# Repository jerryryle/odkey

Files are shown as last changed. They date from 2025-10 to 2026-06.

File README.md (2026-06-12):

# ODKey - A USB HID macro key, with a fun WiFi backdoor

You can find an explanation for this device's existence in [the docs](https://jerryryle.github.io/odkey/).

The ODKey is a hardware device featuring a single button (a [NovelKeys Big Switch](https://novelkeys.com/collections/switches/products/the-big-switch-series)), a USB interface, and a WiFi interface.

When plugged into a computer, the ODKey enumerates as a USB HID keyboard. You can press the ODKey's button to run a configurable script that sends keyboard events to the connected computer. See [ODKeyScript.md](ODKeyScript.md) for documentation on the scripting language used to send keyboard events.

The ODKey incorporates an [Adafruit Feather ESP32-S2](https://www.adafruit.com/product/5000) board. Those familiar with this product will note that, besides the USB interface, the ESP32-S2 sports a WiFi interface. And, of course, the ODKey offers WiFi functionality.

You can use both USB and WiFi to configure the ODKey and run programs.

## Overview of functionality

* The Button
    * A push/release of the ODKey button runs the current flash program (more on this below)
    * If the ODKey is held, it will repeatedly run the flash program as long as it remains held. While held, the ODKey will run the program completion, wait a configurable amount of time (as determined by the `button_repeat` setting), and then run the program again, etc. Once the button is released, any currently-running program will finish and then program execution will stop.
    * Pressing the ODKey button will not interrupt a running program. If you have uploaded a very long program and executed it by pressing the button, the only way to halt it is to physically unplug the ODKey.
    * The ODKey will not enqueue presses. When you press/release the button, two things can happen:
        * The ODKey is idle and begins executing the flash program
        * The ODKey is already executing a program and ignores the new button press.
* ODKeyScript Programs
    * ODKeyScript Programs are compiled locally using the ODKey Tools. Compiled bytecode is uploaded to the device via USB or WiFi.
    * An ODKeyScript Program can be uploaded to flash via USB or WiFi. When the button is pressed, it runs the program currently stored in flash. Flash is non-volatile storage and persists when the device is unplugged/re-plugged or otherwise rebooted.
    * An ODKeyScript Program can be uploaded to RAM and executed immediately. This is an ephemeral program meant for testing and/or remote control of a computer.
    * See [ODKeyScript.md](ODKeyScript.md) for documentation of the ODKeyScript language used to write programs.
* Configuration
    * The ODKey can be configured via USB and/or WiFi.

## Setting up the ODKey Tools on macOS

### Prerequisites

1. **Install Homebrew** (if not already installed):
   See the [Homebrew installation guide](https://brew.sh/#install).

2. **Install Python 3.12+**:
   ```bash
   # Install Python 3.12+ via Homebrew
   brew install python@3.12
   ```

3. **Install uv**:
   ```bash
   # Install uv (Python package manager) via Homebrew
   brew install uv
   ```

4. **Verify installations**:
   ```bash
   python3 --version  # Should show Python 3.12.x or higher
   uv --version       # Should show uv version
   ```

### Clone and Setup the Repository

1. **Clone the ODKey repository**:
   ```bash
   git clone git@github.com:jerryryle/odkey.git
   ```

2. **Navigate to the tools directory**:
   ```bash
   cd odkey/odkey_tools
   ```

3. **Install dependencies and setup the project**:
   ```bash
   # Install project dependencies
   uv sync
   
   # Verify the CLI is working
   uv run odkey --help
   ```

## Using the ODKey Tools
### Device Interfaces
#### USB
The USB interface provides direct communication with the ODKey device using a custom HID protocol. Use this to perform initial configuration before WiFi is set up.

#### WiFi
The WiFi interface provides access to the ODKey device via an HTTP API. This allows you to control and configure the device without a physical USB connection. By default, the ODKey device appears on the network as `odkey.local` via mDNS.

The WiFi credentials, hostname, http port, and API key are all configurable. Use the USB interface for initial setup or if you don't otherwise have WiFi connectivity.

### Device Configuration

The ODKey device stores configuration values in NVS (Non-Volatile Storage) flash memory. You can read, write, and delete these configuration keys using the CLI tools.

#### Supported Configuration Keys

| Key | Type | Description | Default |
|-----|---|---|---|
| `wifi_ssid` | string | WiFi network name (SSID) to connect to | Empty (WiFi not enabled) |
| `wifi_pw` | string | WiFi network password | Empty (WiFi not enabled) |
| `mdns_hostname` | string | mDNS hostname for network discovery | "odkey" |
| `mdns_instance` | string | mDNS instance name for device identification | "ODKey Device" |
| `http_port` | u16 | HTTP server port for WiFi API access | 80 |
| `http_api_key` | string | API key for HTTP authentication | Empty (API disabled) |
| `button_debounce` | u32 | Button debounce time in milliseconds | 50ms |
| `button_repeat` | u32 | Button repeat delay in milliseconds | 225ms |

- **WiFi Configuration**: `wifi_ssid` and `wifi_pw` control which WiFi network the device connects to. If not set, the device operates in USB-only mode.
- **mDNS Discovery**: `mdns_hostname` sets the device's network hostname (e.g., "odkey.local"). `mdns_instance` sets the friendly name shown in network discovery tools.
- **HTTP Server**: `http_port` sets the port for the WiFi API server. `http_api_key` enables authentication for all HTTP operations.
- **Button Behavior**: `button_debounce` prevents false triggers from electrical noise when the button is pressed. `button_repeat` controls how long to wait before re-running the program while the button is held.

#### Configuration Commands

```bash
# Set/get WiFi credentials
## USB
uv run odkey nvs-set wifi_ssid "MyWiFiNetwork"
uv run odkey nvs-set wifi_pw "MyWiFiPassword"

uv run odkey nvs-get wifi_ssid
uv run odkey nvs-get wifi_pw

## HTTP
uv run odkey nvs-set wifi_ssid "MyWiFiNetwork" --interface http --host odkey.local --api-key your-api-key
uv run odkey nvs-set wifi_pw "MyWiFiPassword" --interface http --host odkey.local --api-key your-api-key

uv run odkey nvs-get wifi_ssid --interface http --host odkey.local --api-key your-api-key
uv run odkey nvs-get wifi_pw --interface http --host odkey.local --api-key your-api-key

# Set/get mDNS configuration
## USB
uv run odkey nvs-set mdns_hostname "my-odkey"
uv run odkey nvs-set mdns_instance "My ODKey Device"

uv run odkey nvs-get mdns_hostname
uv run odkey nvs-get mdns_instance

## HTTP
uv run odkey nvs-set mdns_hostname "my-odkey" --interface http --host odkey.local --api-key your-api-key
uv run odkey nvs-set mdns_instance "My ODKey Device" --interface http --host odkey.local --api-key your-api-key

uv run odkey nvs-get mdns_hostname --interface http --host odkey.local --api-key your-api-key
uv run odkey nvs-get mdns_instance --interface http --host odkey.local --api-key your-api-key

# Set/get HTTP server configuration
## USB
uv run odkey nvs-set http_port 8080 --type u16
uv run odkey nvs-set http_api_key "my-secret-api-key"

uv run odkey nvs-get http_port
uv run odkey nvs-get http_api_key

## HTTP
uv run odkey nvs-set http_port 8080 --type u16 --interface http --host odkey.local --api-key your-api-key
uv run odkey nvs-set http_api_key "my-secret-api-key" --interface http --host odkey.local --api-key your-api-key

uv run odkey nvs-get http_port --interface http --host odkey.local --api-key your-api-key
uv run odkey nvs-get http_api_key --interface http --host odkey.local --api-key your-api-key

# Set/get button behavior
## USB
uv run odkey nvs-set button_debounce 100 --type u32
uv run odkey nvs-set button_repeat 500 --type u32

uv run odkey nvs-get button_debounce
uv run odkey nvs-get button_repeat

## HTTP
uv run odkey nvs-set button_debounce 100 --type u32 --interface http --host odkey.local --api-key your-api-key
uv run odkey nvs-set button_repeat 500 --type u32 --interface http --host odkey.local --api-key your-api-key

uv run odkey nvs-get button_debounce --interface http --host odkey.local --api-key your-api-key
uv run odkey nvs-get button_repeat --interface http --host odkey.local --api-key your-api-key

# Delete configuration keys
## USB
uv run odkey nvs-delete wifi_ssid # disables WiFi
uv run odkey nvs-delete http_api_key # disables HTTP API

## HTTP
uv run odkey nvs-delete wifi_ssid --interface http --host odkey.local --api-key your-api-key # disables WiFi
uv run odkey nvs-delete http_api_key --interface http --host odkey.local --api-key your-api-key # disables HTTP API
```

### Program upload/execution

When you push the ODKey's button, it runs a program stored in flash. You can update this program over the USB/HTTP interfaces. The ODKey has a little less than 1MB reserved for the flash program.

You can also upload a temporary program over USB/HTTP to the ODKey's RAM and execute it immediately. The largest program you can upload to RAM is 1MB.

#### Compile and disassemble programs
The ODKey Tools include a compiler to compile ODKeyScript and a disassembler that takes a compiled program and outputs the ODKeyScript Virtual Machine opcodes. Note that the ODKey Tools upload command can automatically compile an ODKeyScript file for you before uploading it, so you do not need to invoke the compiler yourself.

```bash
# Compile an ODKeyScript program to bytecode
uv run odkey compile scripts/sample.odk sample.bin

# Disassemble the compiled bytecode to see the opcodes
uv run odkey disassemble sample.bin
```

#### Upload a Program
```bash
# Upload an ODKeyScript source file (compiles automatically)
## RAM
uv run odkey upload program.odk
## Flash
uv run odkey upload --target flash scripts/sample.odk

# Upload pre-compiled bytecode
## RAM
uv run odkey upload program.bin
## flash
uv run odkey upload --target flash program.bin
```

#### Upload and execute a program
```bash
# Upload ODKeyScript source and execute immediately (compiles automatically)
## RAM
uv run odkey upload --execute scripts/sample.odk
## flash
uv run odkey upload --execute --target flash scripts/sample.odk
```

#### Execute a program
```bash
# Executes a previously-uploaded program
## RAM
uv run odkey execute
## flash
uv run odkey execute --target flash
```

#### Download a Program
```bash
# Download program
## RAM
uv run odkey download --output program.bin
## flash
uv run odkey download --target flash --output program.bin

# Download program and disassemble it
## RAM
uv run odkey download --disassemble
## flash
uv run odkey download --target flash --disassemble
```

### Log Management

The ODKey device maintains a 32KB ring buffer in PSRAM that captures all ESP32 log output (ESP_LOGI, ESP_LOGE, etc.). Logs continue to be sent to the serial port as normal while also being captured to the ring buffer for download.

#### Download Logs
```bash
# Download logs from device (displays to console)
uv run odkey log

# Save logs to file
uv run odkey log --output logs.txt

# Download via HTTP interface
uv run odkey log --interface http --host odkey.local --api-key key
```

#### Clear Log Buffer
```bash
# Clear the log buffer on the device
uv run odkey log-clear

# Clear via HTTP interface
uv run odkey log-clear --interface http --host odkey.local --api-key key
```

## Known issues

* There is an occasional corruption issue when downloading logs. It seems to be correlated with attempts to download logs while logs are being generated. It may only occur over the USB interface. It has not been tested well enough to know for sure.

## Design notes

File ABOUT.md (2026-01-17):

# About the ODKey (November 2025)

I made the ODKey to prank my coworker and send messages from him in Slack. It almost worked, but I forgot to revert my script from a test channel to a real one. Ah well, next time. He caught it furiously trying to type to a non-existent channel. I've never seen someone unplug a USB device that fast.

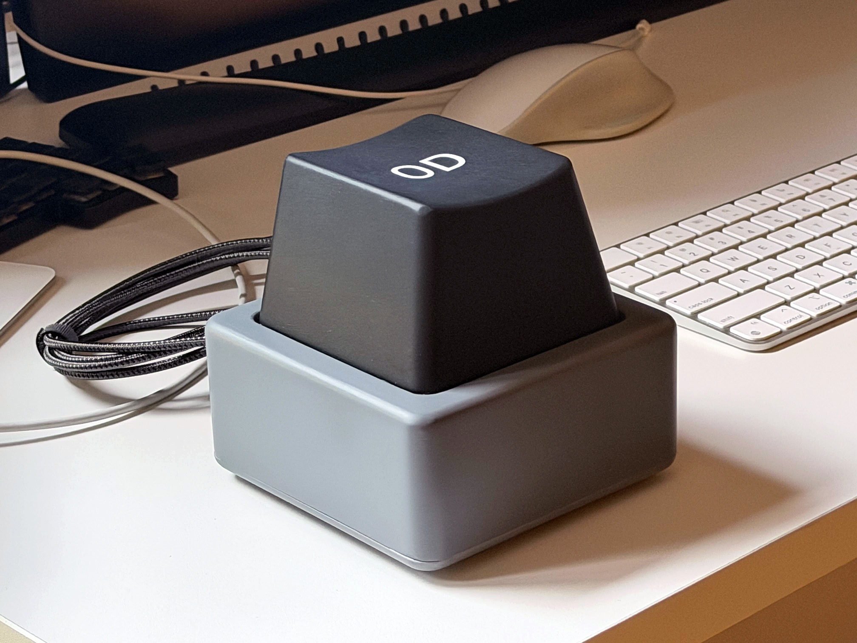
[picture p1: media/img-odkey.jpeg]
The ODKey Photo of the ODKey at OD's desk


You can find technical information and instructions for ODKey use in [README.md](/README.md).

I bought a 3D printer earlier this year and I've been printing random things for my coworkers. Usually, they'll find a model on a site like [makerworld](https://makerworld.com) and send it to me for printing. It doesn't take much effort on my part to print these & it's helped me learn more about the printer and 3D printing in general.

Near the end of September, I announced in Slack:
> Me: My 3D printer will be idle for a bit, if anyone wants something printed. I promise not to put teeth in it, unless you ask.

The teeth thing is a running joke from a previous prank. Ignore that. What's important is that one of my coworkers, OD, replied:
>OD: Can I get a single functioning keycap the size of a normal macbook keyboard? Feel free to add teeth to it.

The context here is that giant keyboards had become a meme at work, with people bringing in [ridiculously-large keyboards](https://www.amazon.com/Redragon-Mechanical-Keyboard-Ergonomic-Anti-Ghosting/dp/B09V4HTWLT) and holding typing contests.

>Me: You want one big keycap to cover your MacBook keyboard? And what does "functional" entail here?

>OD: It can be pressed. Not to cover, just the size of it. No need to send input, just be physically clicky like one of [other coworker]'s giant keys

>Me: Oh. I see. Hm unless you can find an existing design online, that requires Jerry’s Design Services, which are a scarce resource.

>OD: I think it should be possible to just scale up a mx keycap stl to have the stem slots fit a kailh giant switch, a spacebar with multiple stem slots scaled up to that amount would probably be the easiest

>Me: Hmm. We’ll see if Jerry’s Design Services get bored enough to try that. If they are, what would the key silkscreen be? Spacebar (blank)? Letter/number? Etc.

>OD: I think it could be blank, or if Jerry's design services are amused to, maybe [our company name] or something like that on a space bar

Now, I generally don't target individuals with pranks, but I felt that this coworker had just opted himself into one. And Jerry's Design Services did get very bored, so I decided to take on his request...with some modifications that would be more fun for me.

First, the key would be large, but not the size of a MacBook keyboard. That would have required more mechanical design work than I cared to take on and would also take much longer to print. So, I decided I would create a more manageable 100mm x 100mm x 65mm keycap. This would be comically large, but wouldn't require more mechanical stabilization than an off-the-shelf switch could provide.

Second, the key would be functional--not just in that it could be pressed and make a click sound. It would enumerate as a USB HID keyboard and, when you pushed the button, it would emit key presses. I decided to implement a rudimentary scripting language so that the button's function could be updated. By default, it would type my coworker's initials, "OD"; hence, I would call it the "ODKey."

Third, and this was very important, it would contain a WiFi radio and HTTP interface that would let me send keypresses of my choosing to whatever computer the ODKey is plugged into.

To begin, I sourced a large mechanical key because I didn't want to create the switch mechanism from scratch. I found the [NovelKeys Big Switch series](https://novelkeys.com/collections/switches/products/the-big-switch-series?variant=3747938500648) and purchased the [blue Clicky](https://www.adafruit.com/product/5307) model from Adafruit.

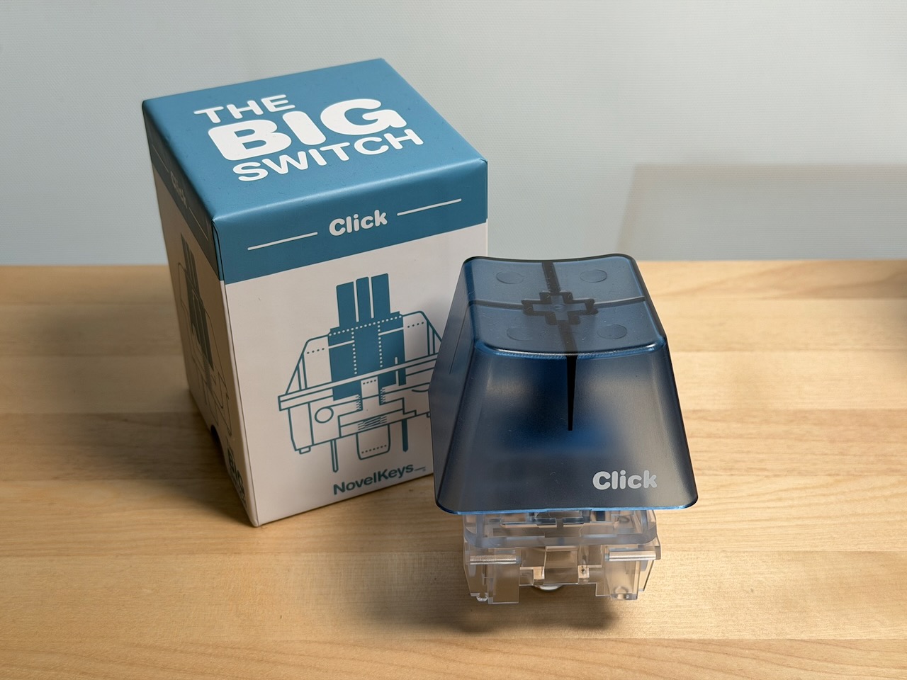
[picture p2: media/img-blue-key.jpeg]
The Blue Big Switch Photo of a blue Big Switch next to the box it came in


Next, I needed a microcontroller that had both USB device and WiFi functionality. The [Espressif ESP32-S2](https://www.espressif.com/en/products/socs/esp32-s2) has both. Adafruit offers the [ESP32-S2 Feather](https://www.adafruit.com/product/5000) which incorporates the ESP32-S2 onto a PCBA with a nice, small form-factor.

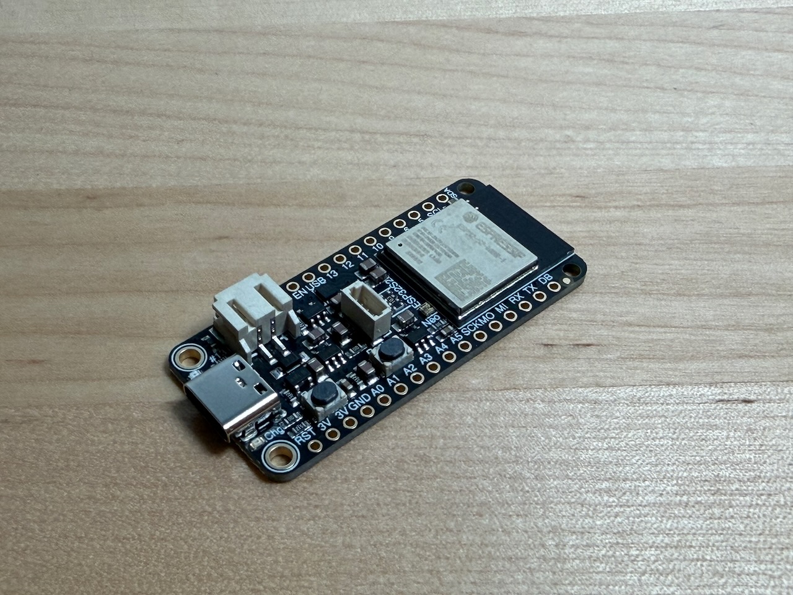
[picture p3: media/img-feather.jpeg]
The ESP32-S2 Feather Photo of an ESP32-S2 PCBA on my desk


I took measurements from the blue keycap that came with the Big Switch and roughly used these to model my own keycap, scaling it up about 1.4x.

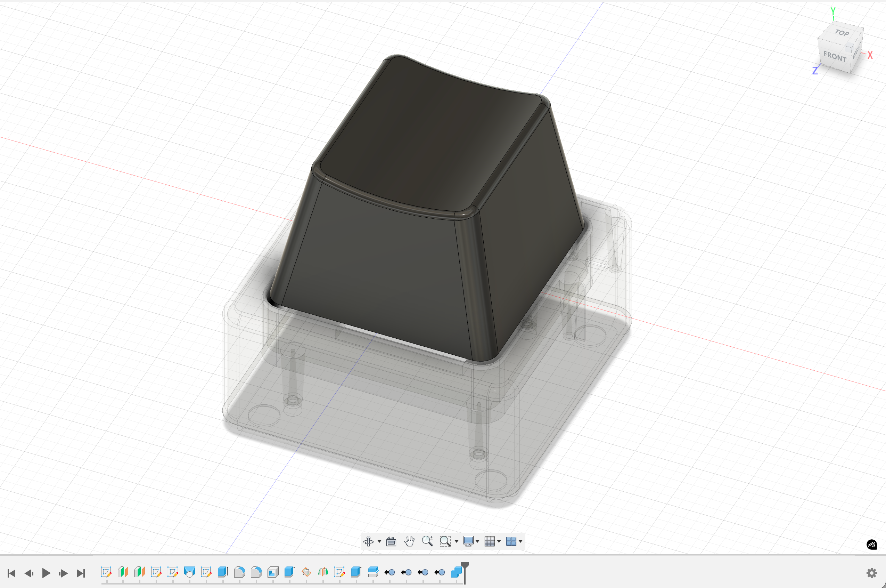
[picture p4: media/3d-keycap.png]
Keycap Screenshot of a 3D CAD model of the keycap


This was an early test print I did to ensure I had the geometry and tolerances right for the part of the keycap that would slide over the switch's stem.

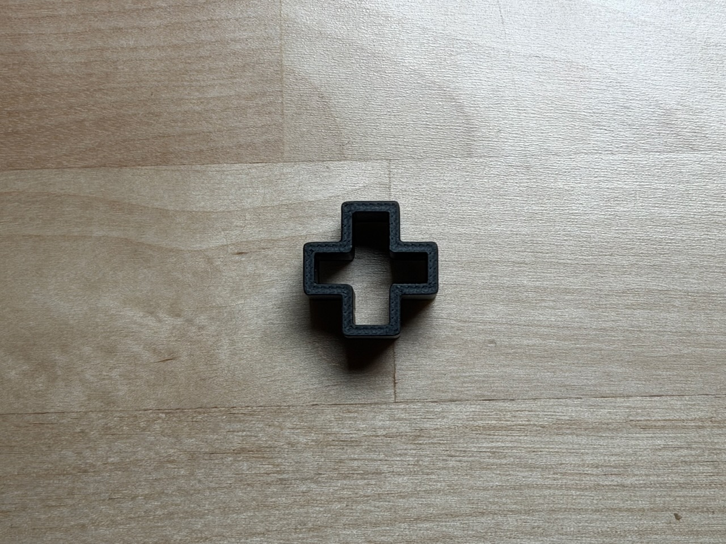
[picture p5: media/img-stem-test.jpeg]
Stem test print Photo of a cross-shaped 3D print


I then modeled a base that the big key snaps into. The base also holds the ESP32-S2 Feather PCBA. I modeled the base in two parts, with a bottom that I could screw on after assembling the switch and PCBA.

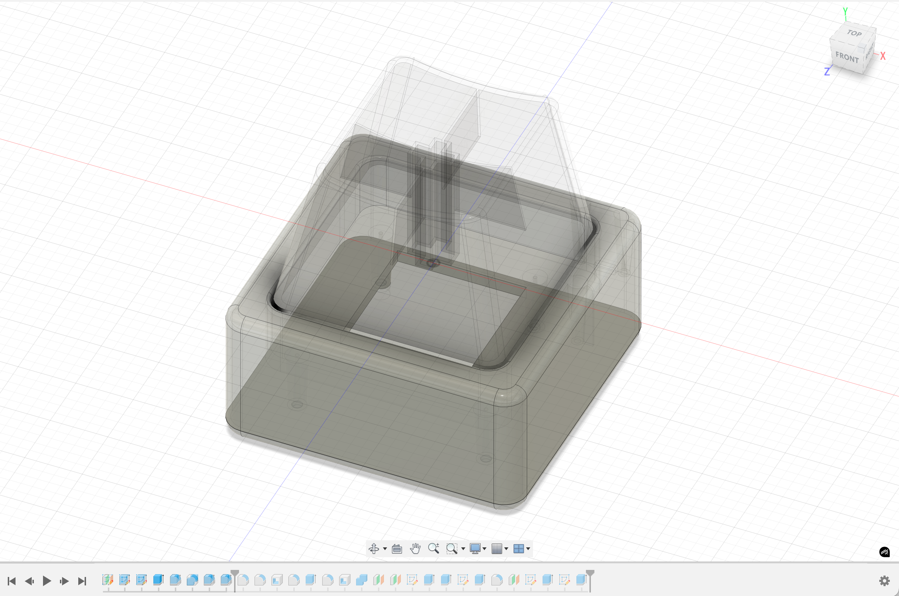
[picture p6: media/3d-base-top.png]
Base top Screenshot of a 3D CAD model of the top portion of the base


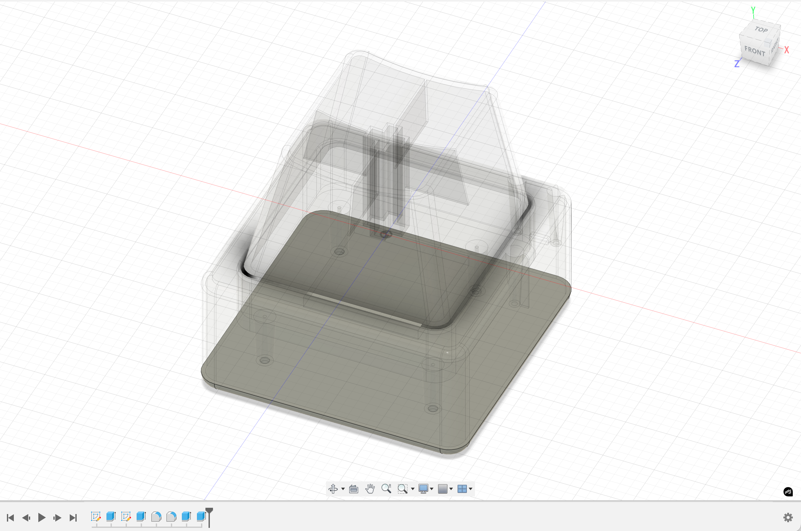
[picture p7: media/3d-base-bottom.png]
Base bottom Screenshot of a 3D CAD model of the bottom portion of the base


I printed everything in matte PLA using my Bambu Labs H2D.

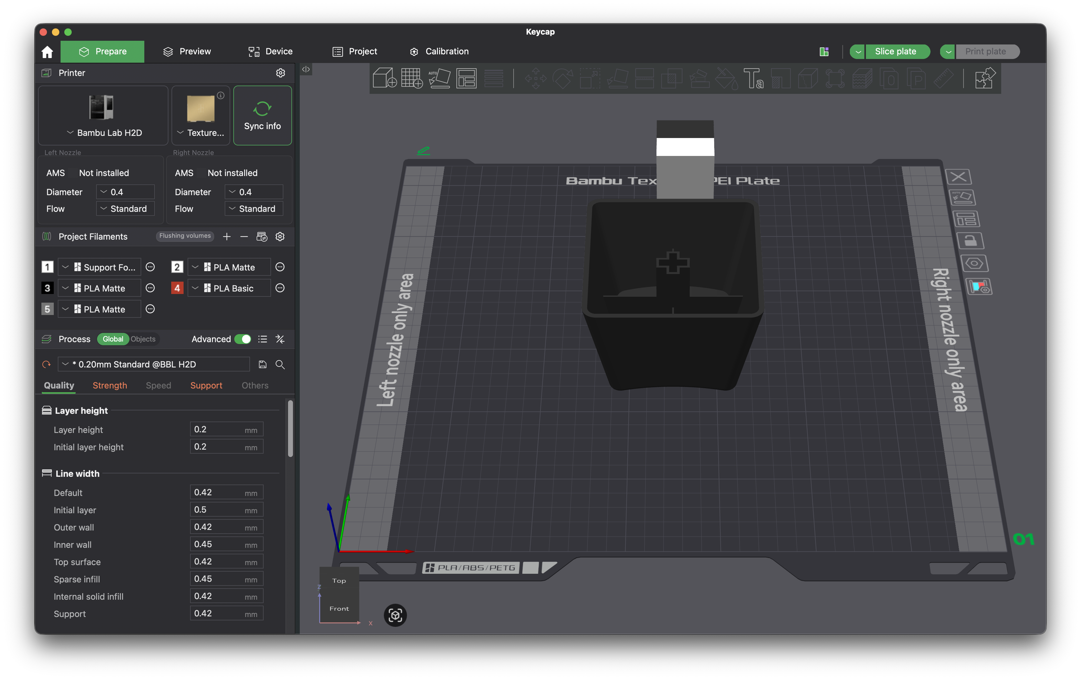
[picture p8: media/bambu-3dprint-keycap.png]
Keycap print preparation Screenshot of the keycap in Bambu Studio

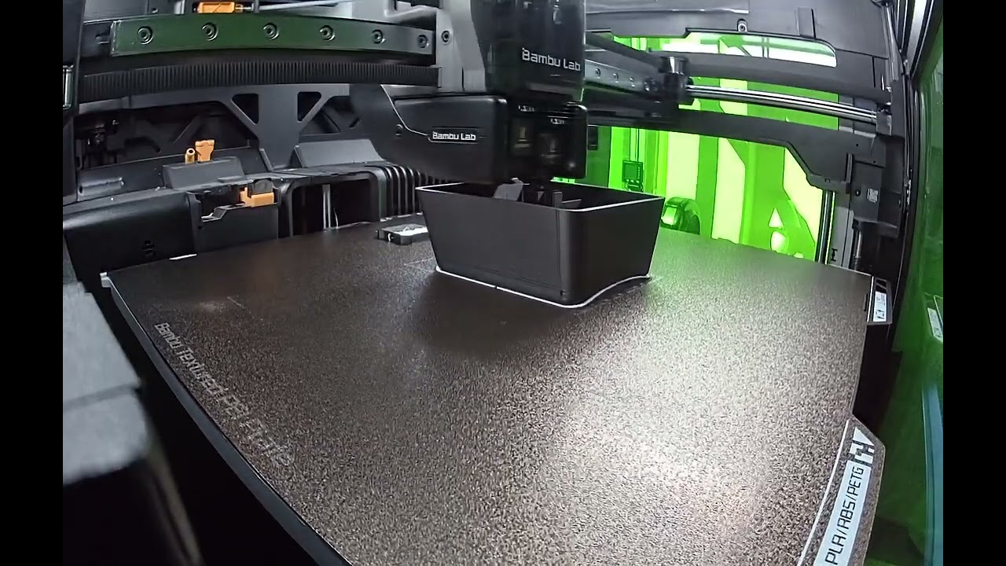
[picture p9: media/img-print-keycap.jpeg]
Keycap printing Time lapse video of the keycap 3D printing (https://youtu.be/hejnoI1uLic)


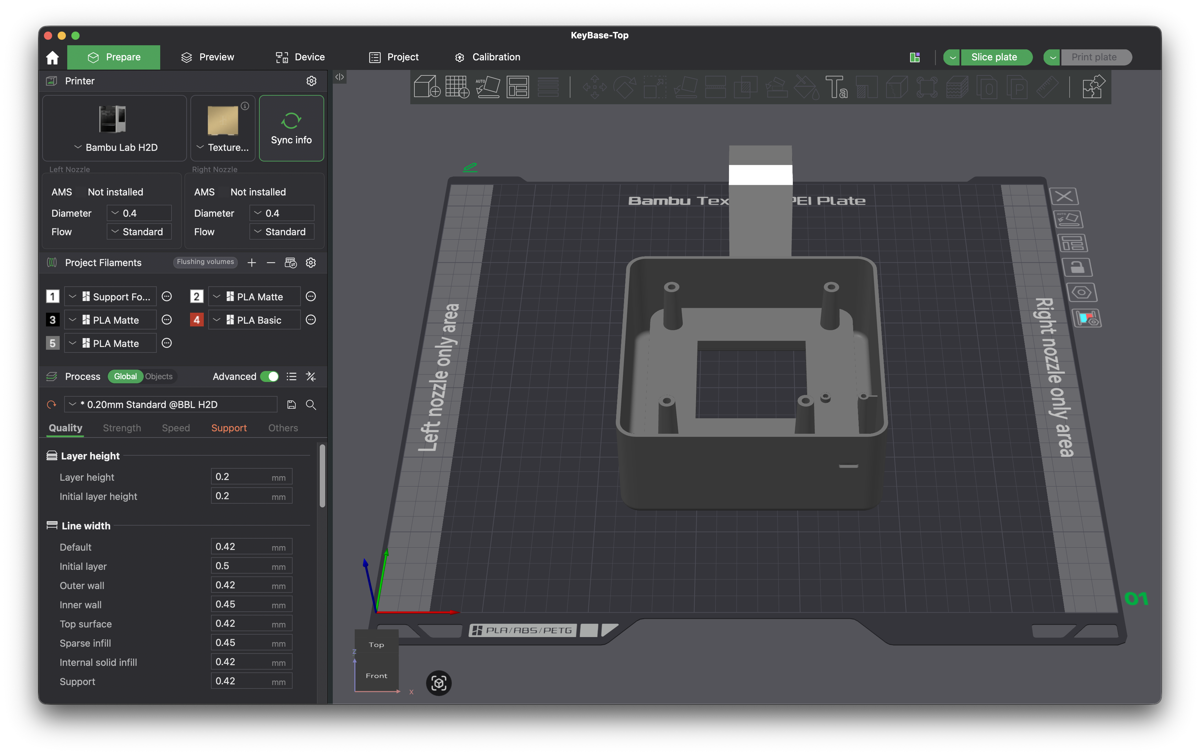
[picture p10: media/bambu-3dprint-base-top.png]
Base top print preparation Screenshot of the base top in Bambu Studio

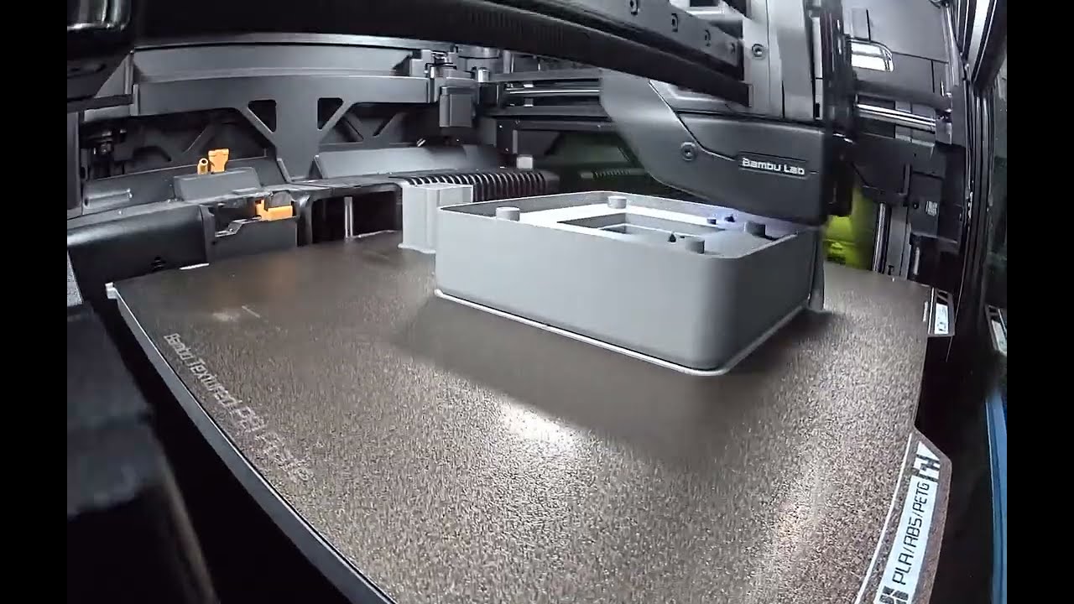
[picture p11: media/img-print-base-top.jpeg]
Base top printing Time lapse video of the base top 3D printing (https://youtu.be/YH3hyE5TDeQ)


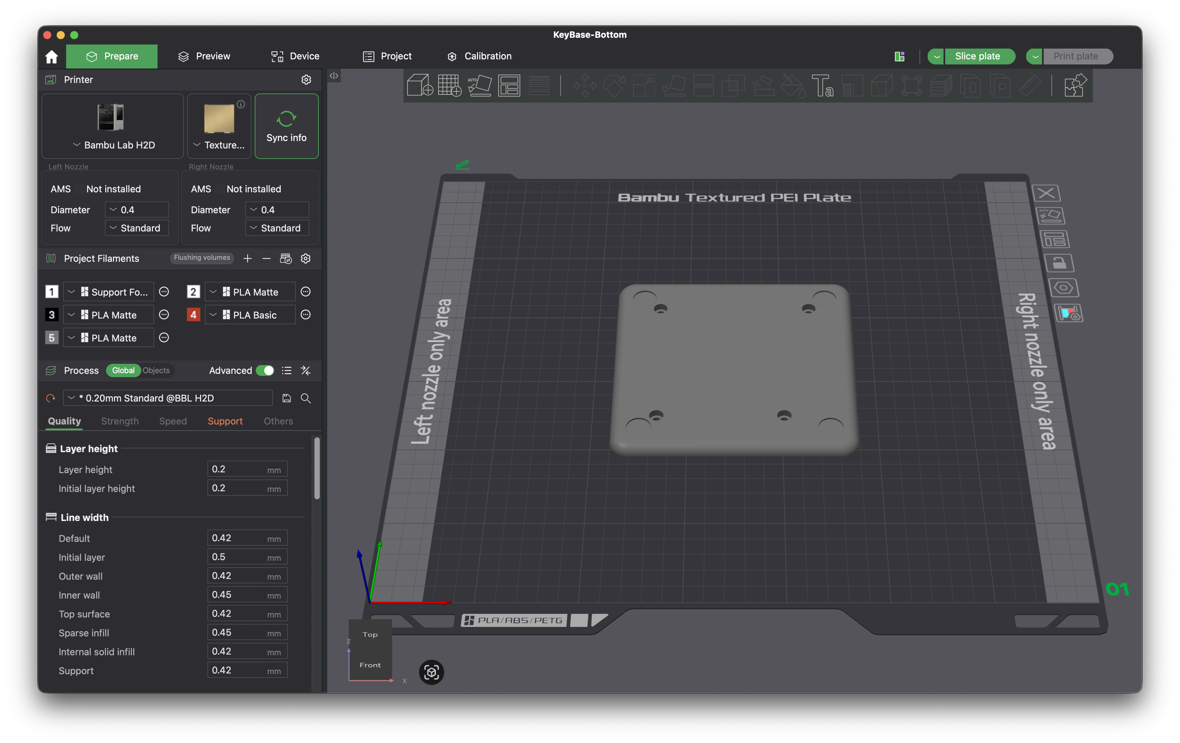
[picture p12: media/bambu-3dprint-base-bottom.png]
Base bottom print preparation Screenshot of the base bottom in Bambu Studio

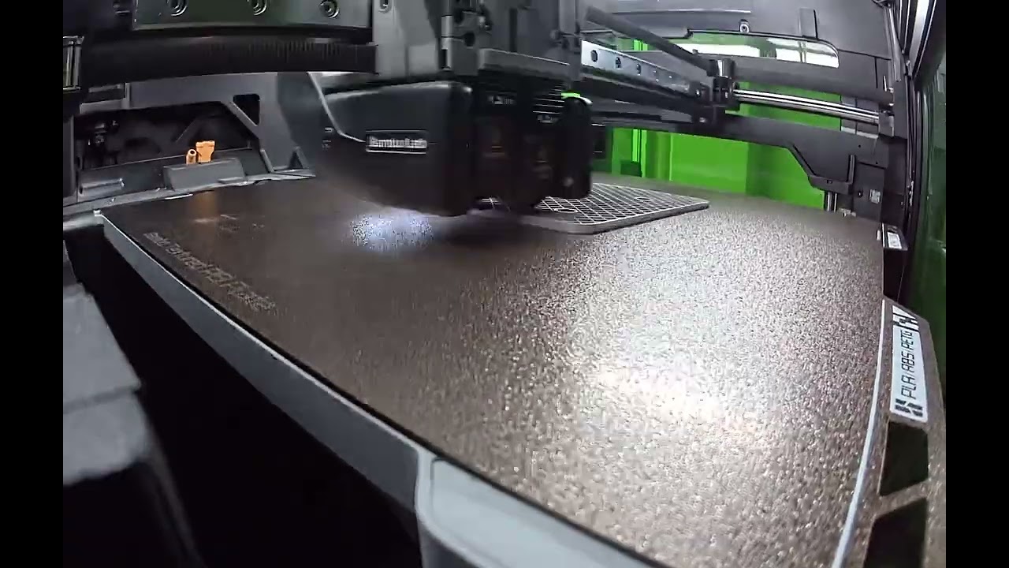
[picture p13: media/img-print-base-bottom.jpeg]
Base bottom printing Time lapse video of the base bottom 3D printing (https://youtu.be/WQhLJaSar2g)


I had never tried making a cosmetic model before, so I decided to give it a shot instead of using the raw 3D printed parts. This involved a ton of sanding, priming, sanding, filling, sanding, priming, sanding, and painting. The goal was to turn the raw print:

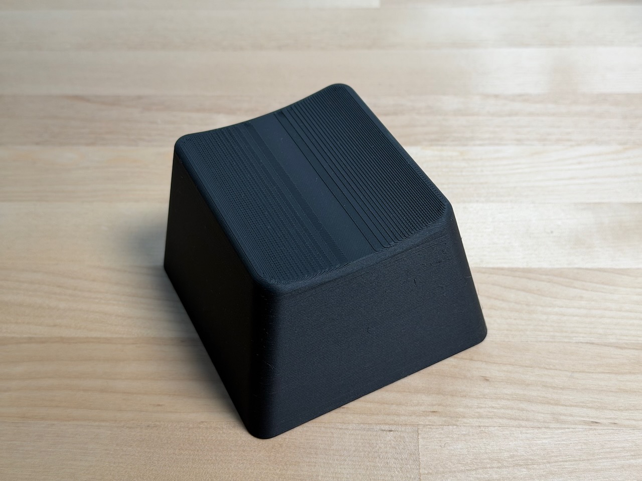
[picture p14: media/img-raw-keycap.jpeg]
Raw keycap 3D Print Photo of the raw 3D print of the keycap, with its layer lines from the 3D printing process


into a nicer-looking version with a refined surface finish and a label:

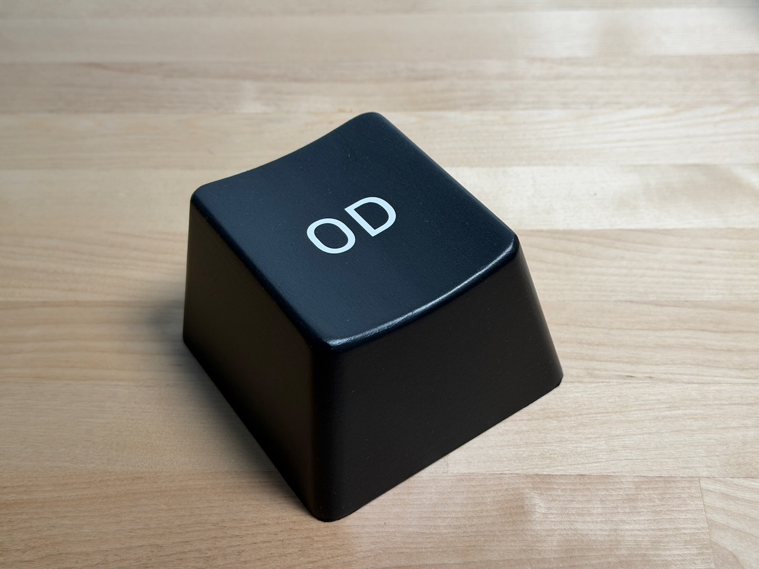
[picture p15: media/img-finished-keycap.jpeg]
Finished keycap 3D Print Photo of the finished 3D print of the keycap, with a smooth surface finish and 'OD' key label.


It took a few tries and I still need to hone my sanding/painting skills more, but I'm pretty happy with how it turned out. Here's the whole thing, freshly assembled.

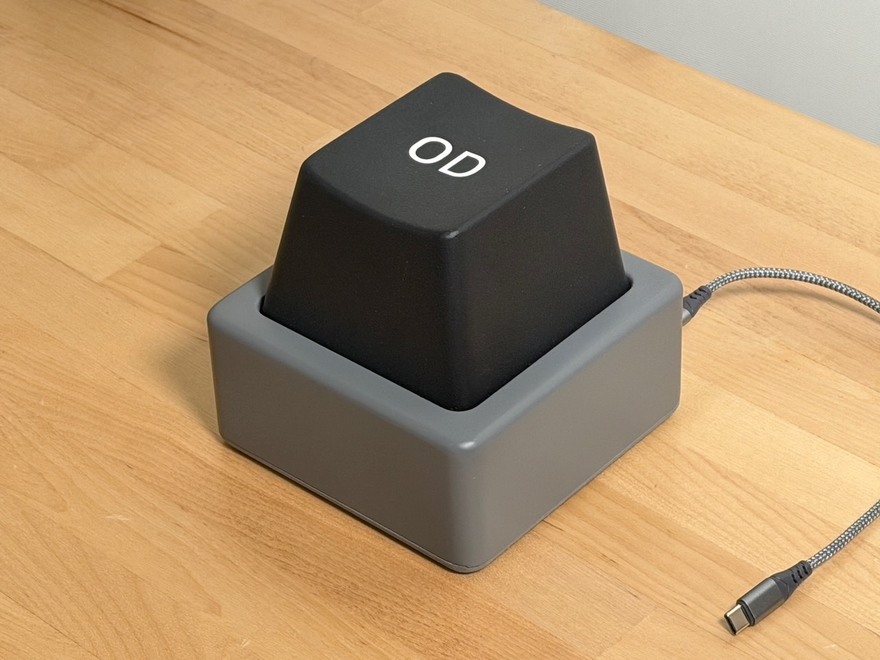
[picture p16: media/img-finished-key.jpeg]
Finished ODKey Photo of the finished and fully-assembled ODKey.


A few key lessons:

* Primer is insufficient to fill deeper cracks. If you try to build up a base of primer that's thick enough to fill them, you'll wind up with a gummy mess when sanding. Use putty to fill deeper cracks. I had watched some videos that warned about this, but I thought the cracks I was filling with primer were small enough to get away with. They were not and I used too much primer.
* If the surface isn't perfectly smooth before painting, imperfections will stand out once painted. This may seem obvious, but I had a few small surface imperfections that I could feel but not easily see. Once painted, they clearly stood out.
* Paint in very light coats, keeping the can at a distance, in order to prevent drips that look terrible. I wound up with a few small ones. Supposedly you can sand them down and re-paint, but I was tired of sanding and painting by that point.
* If you have mating parts, mate them and prime/sand them together. The parting line on my base top/bottom is more prominent than it should be because I primed and sanded them separately.
* Don't leave painted PLA models in direct sunlight to dry! PLA softens at relatively low temperatures. Both halves of my base warped irreparably because I left them in the sun to dry after their first coat of paint. A huge waste of time spent on printing/sanding/priming.
* Don't put too much clear coat on at once. I did this by accident to the first keycap that I had sanded and painted perfectly and destroyed it with a wrinkled texture.

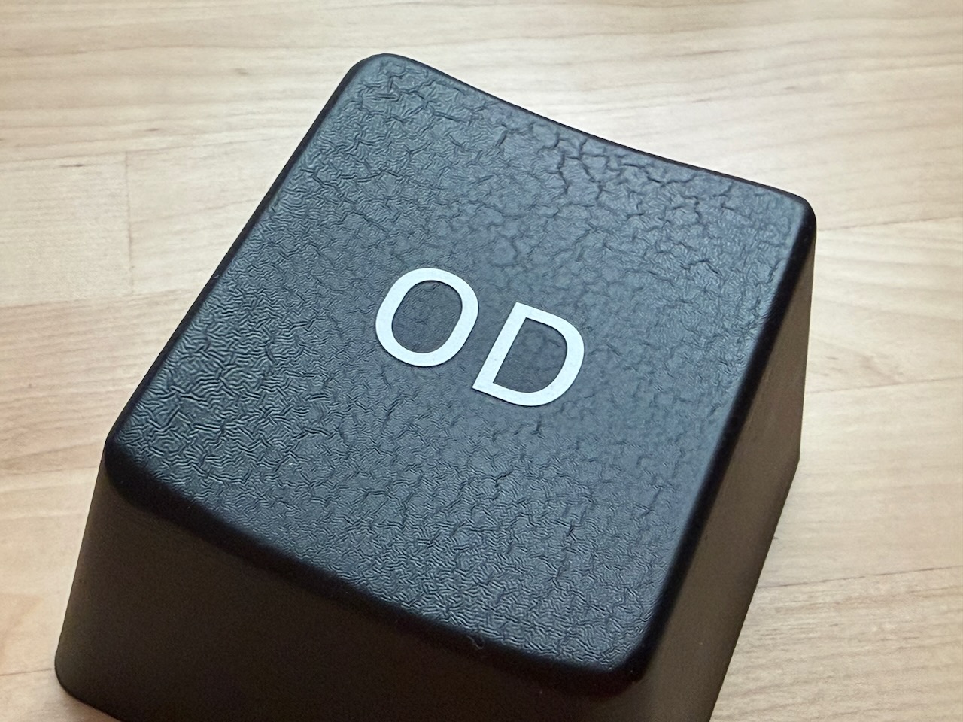
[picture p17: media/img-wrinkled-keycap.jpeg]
Wrinkled keycap Photo of a keycap that has a wrinkled texture due to too much clear coat


All the waiting for printing and paint to dry gave me plenty of time to work on the ODKey firmware. I largely vibe-coded it using Cursor, which did reasonably well with supporting Python scripts, though it struggled a bit with the firmware. I began with a simple USB HID device that pressed/released the "A" key 1 second after it was plugged into a USB host. Cursor created a reasonable framework for this, though it made several mistakes in the USB descriptor that I had to hunt down and fix. And, as I added to the codebase, I found myself often fixing thread-safety issues that Cursor introduced.

I knew that I wanted to use a scripting language for the keypress functionality so that the device could be easily user-reprogrammed. I looked into [DuckyScript™](https://docs.hak5.org/hak5-usb-rubber-ducky/usb-rubber-ducky-by-hak5/), but couldn't be arsed to read the huge license for it. It had way more functionality than I needed anyways, so I decided to roll my own.

I wrote the [ODKeyScript](ODKeyScript.md) specification and told Cursor to generate a Python compiler, a Python disassembler, and a C VM for the language. It did this task surprisingly well. Having the disassembler helped me verify that the compiler was behaving as expected and I found and fixed a few small issues that stemmed from under-specification. The VM that Cursor produced was straightforward and reasonable.

I now have an ODKey hardware device that enumerates as a USB keyboard and runs a pre-programmed ODKeyScript when the button is pushed. I can connect to the ODKey remotely via WiFi and upload/run ODKeyScripts using an HTTP interface protected with an API key. I have created and tested a series of scripts that let me launch Slack and say entertaining things on behalf of the poor soul who has plugged the ODKey into their computer.

This should be fun. And, once fun has been had, I'll point my coworker to this repo so he can see how to reprogram and enjoy his giant macro key.

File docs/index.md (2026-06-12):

---
title: "(November 2025) ODKey: A USB HID macro key, with a fun WiFi backdoor"
---
# Background
You can find more technical detail and usage instructions in the [ODKey repo](https://github.com/jerryryle/odkey).

I made the ODKey to prank my coworker and send messages to our entire company from his Slack account. It almost worked, but I forgot to revert my script from a test channel to a real one, so he caught it furiously trying to type to a non-existent channel. I've never seen someone unplug a USB device that fast. Ah well, next time.

The ODKey Photo of the ODKey at OD's desk

I bought a 3D printer earlier this year and have been printing random things for my coworkers. Usually, they'll find a model on a site like [makerworld](https://makerworld.com) and send it to me for printing. These prints take little effort on my part, and they've helped me learn more about the printer and 3D printing in general.

Near the end of September, I announced in Slack:
> Me: My 3D printer will be idle for a bit, if anyone wants something printed. I promise not to put teeth in it, unless you ask.

The teeth thing is a running joke from a previous prank. Ignore that. What's important is that one of my coworkers, OD, replied:
>OD: Can I get a single functioning keycap the size of a normal macbook keyboard? Feel free to add teeth to it.

For context: giant keyboards had become a meme at work, with people bringing in [ridiculously large keyboards](https://www.amazon.com/Redragon-Mechanical-Keyboard-Ergonomic-Anti-Ghosting/dp/B09V4HTWLT) and holding typing contests.

>Me: You want one big keycap to cover your MacBook keyboard? And what does "functional" entail here?

>OD: It can be pressed. Not to cover, just the size of it. No need to send input, just be physically clicky like one of [other coworker]'s giant keys

>Me: Oh. I see. Hm unless you can find an existing design online, that requires Jerry’s Design Services, which are a scarce resource.

>OD: I think it should be possible to just scale up a mx keycap stl to have the stem slots fit a kailh giant switch, a spacebar with multiple stem slots scaled up to that amount would probably be the easiest

>Me: Hmm. We’ll see if Jerry’s Design Services get bored enough to try that. If they are, what would the key silkscreen be? Spacebar (blank)? Letter/number? Etc.

>OD: I think it could be blank, or if Jerry's design services are amused to, maybe [our company name] or something like that on a space bar

Now, I generally don't target individuals with pranks, but this coworker had just opted himself into one. And Jerry's Design Services did get very bored, so I decided to take on his request, with a few modifications that would be more fun for me.

First, the key would be large, but not the size of a MacBook keyboard. That would have required more mechanical design work than I cared to take on, and a much longer print. Instead, I settled on a more manageable 100mm x 100mm x 65mm keycap: still comically large, but not so large that it would need more mechanical stabilization than an off-the-shelf switch could provide.

Second, the key would be functional, and not just in the sense that it could be pressed and make a click sound. It would enumerate as a USB HID keyboard and emit key presses when pushed. I decided to implement a rudimentary scripting language so that the button's function could be updated. By default, it would type my coworker's initials, "OD"—hence the name "ODKey."

Third, and this was very important, it would contain a WiFi radio and an HTTP interface that would let me send keypresses of my choosing to whatever computer the ODKey was plugged into.

# The Making Of
To begin, I sourced a large mechanical switch because I didn't want to create the switch mechanism from scratch. I found the [NovelKeys Big Switch series](https://novelkeys.com/collections/switches/products/the-big-switch-series?variant=3747938500648) and purchased the [blue Clicky](https://www.adafruit.com/product/5307) model from Adafruit.

The Blue Big Switch Photo of a blue Big Switch next to the box it came in

Next, I needed a microcontroller with both USB device and WiFi functionality. The [Espressif ESP32-S2](https://www.espressif.com/en/products/socs/esp32-s2) has both, and Adafruit offers the [ESP32-S2 Feather](https://www.adafruit.com/product/5000), which puts the chip on a PCBA with a nice, small form factor.

The ESP32-S2 Feather Photo of an ESP32-S2 PCBA on my desk

I took measurements from the blue keycap that came with the Big Switch and used them as a rough guide to model my own keycap, scaled up about 1.4x.

Keycap Screenshot of a 3D CAD model of the keycap

This was an early test print to make sure I had the geometry and tolerances right for the part of the keycap that slides over the switch's stem.

Stem test print Photo of a cross-shaped 3D print

I then modeled a base that the big switch snaps into and that also holds the ESP32-S2 Feather PCBA. I split the base into two parts so that I could screw on the bottom after assembling the switch and PCBA.

Base top Screenshot of a 3D CAD model of the top portion of the base

Base bottom Screenshot of a 3D CAD model of the bottom portion of the base

I printed everything in matte PLA on my Bambu Lab H2D.

Keycap print preparation Screenshot of the keycap in Bambu Studio
Keycap printing Time lapse video of the keycap 3D printing (https://youtu.be/hejnoI1uLic)

Base top print preparation Screenshot of the base top in Bambu Studio
Base top printing Time lapse video of the base top 3D printing (https://youtu.be/YH3hyE5TDeQ)

Base bottom print preparation Screenshot of the base bottom in Bambu Studio
Base bottom printing Time lapse video of the base bottom 3D printing (https://youtu.be/WQhLJaSar2g)

I had never tried making a cosmetic model before, so I decided to give it a shot rather than use the raw 3D-printed parts. This involved a ton of sanding, priming, sanding, filling, sanding, priming, sanding, and painting. The goal was to turn the raw print:

Raw keycap 3D Print Photo of the raw 3D print of the keycap, with its layer lines from the 3D printing process

into a nicer-looking version with a refined surface finish and a label:

Finished keycap 3D Print Photo of the finished 3D print of the keycap, with a smooth surface finish and 'OD' key label.

It took a few tries, and I still need to hone my sanding and painting skills, but I'm pretty happy with how it turned out. Here's the whole thing, freshly assembled.

Finished ODKey Photo of the finished and fully-assembled ODKey.

A few key lessons:

* Primer alone won't fill deeper cracks. If you try to build up a base of primer thick enough to fill them, you'll wind up with a gummy mess when sanding. Use putty instead. I had watched videos that warned about this, but I thought my cracks were small enough to get away with primer. They were not.
* If the surface isn't perfectly smooth before painting, imperfections will stand out once painted. This may seem obvious, but I had a few small imperfections that I could feel but not easily see. Once painted, every one of them was clearly visible.
* Paint in very light coats with the can at a distance to prevent drips. I wound up with a few small ones. Supposedly you can sand drips down and re-paint, but by that point I was tired of sanding and painting.
* If you have mating parts, mate them and prime/sand them together. The parting line on my base is more prominent than it should be because I primed and sanded the top and bottom separately.
* Don't leave painted PLA models in direct sunlight to dry! PLA softens at relatively low temperatures. Both halves of my base warped irreparably after I left them in the sun following their first coat of paint—a huge waste of printing, sanding, and priming time.
* Don't put on too much clear coat at once. I accidentally did this to the first keycap—the one I had sanded and painted perfectly—and destroyed it with a wrinkled texture.

Wrinkled keycap Photo of a keycap that has a wrinkled texture due to too much clear coat

All the waiting for prints and paint to dry gave me plenty of time to work on the ODKey firmware. I largely vibe-coded it using Cursor, which did a reasonably good job on the supporting Python scripts but struggled a bit with the firmware. I began with a simple USB HID device that pressed and released the "A" key one second after being plugged into a USB host. Cursor created a reasonable framework for this, though it made several mistakes in the USB descriptor that I had to hunt down and fix. And as I added to the codebase, I often found myself fixing thread-safety issues that Cursor introduced.

I knew I wanted a scripting language for the keypress functionality so that the device could be easily reprogrammed. I looked into [DuckyScript™](https://docs.hak5.org/hak5-usb-rubber-ducky/usb-rubber-ducky-by-hak5/), but couldn't be arsed to read its huge license. It had way more functionality than I needed anyway, so I decided to roll my own.

I wrote the [ODKeyScript](ODKeyScript.md) specification and told Cursor to generate a Python compiler, a Python disassembler, and a C VM for the language. It handled this surprisingly well. The disassembler helped me verify that the compiler was behaving as expected, and I found and fixed a few small issues that stemmed from under-specification. The VM that Cursor produced was straightforward and reasonable.

The result is an ODKey that enumerates as a USB keyboard and runs a pre-programmed ODKeyScript when the button is pushed. I can also connect to it remotely over WiFi and upload and run scripts through an HTTP interface protected with an API key. I've created and tested a series of scripts that let me launch Slack and say entertaining things on behalf of the poor soul who has plugged the ODKey into their computer.

This should be fun. And once the fun has been had, I'll point my coworker to this repo so he can see how to reprogram and enjoy his giant macro key.

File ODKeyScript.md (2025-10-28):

# ODKeyScript Reference
The ODKey can be reprogrammed to perform custom macro sequences that are written in ODKeyScript. This file documents that language and the virtual machine that executes it.

ODKeyScript compilers should fail on the first error encountered.

## Comments
The `#` character denotes a comment. It and everything after it on the same line is ignored.
Example:
```
# This is a comment
KEYDN M_LEFTSHIFT A B C D E F # Presses left shift and abcdef keys all together
```

## Commands
All commands are case sensitive. They can appear anywhere on a line, but a line may only contain one command.

### press_time
The `press_time` command sets the time, in milliseconds that keys are "pressed" for commands such as `press` and `type`. This can be set more than once within a script and it applies to all relevant commands that come after it. Note that very short press times may be unreliable, depending upon the OS and application. ODKey defaults the press time to 30ms.
Example:
```
press_time 30
press ENTER # Short press of enter
press_time 100
press A # Longer press of enter
```

### interkey_time
The `interkey_time` command sets the time, in milliseconds between the last key up and the next key down for sequence commands such as `type`. It also automatically adds a delay after `press`. This can be set more than once within a script and it applies to all relevant commands that come after it. Note that very short interkey times may be unreliable, depending upon the OS and application. ODKey defaults the interkey time to 30ms.
Example:
```
press_time 50
interkey_time 50
# Keys are pressed for 50 ms and there's a delay of 50ms between keystrokes.
type Hello World!
press_time 100
press A # Longer press of enter
```

### pause
The `pause` command pauses execution for the specified number of milliseconds.
```
pause 100
```

### keydn
The `keydn` command "presses" up to 6 keys and any number of modifier keys. The keys and modifiers follow the `keydn` command and may be specified in any order. The keys will appear in the HID report in the order specified (the modifiers are sent as bitmasks and thus have no order). If more than 6 keys are specified, the script will fail to compile. Note that if you send two keydn reports in a row with a different set of keys, the OS will infer key releases for any keys that were included in the first report, but not the second.
Example:
```
keydn M_LEFTSHIFT A B C D E F
pause 100
keyup

keydn A
pause 100
keydn B # The OS will infer that "A" was released here.
pause 100
keyup

```

### keyup
The `keyup` command "releases" up to 6 keys and any number of modifier keys. The keys and modifiers follow the `keyup` command and may be specified in any order. The keys will appear in the HID report in the order specified (the modifiers are sent as bitmasks and thus have no order). If more than 6 keys are specified, the script will fail to compile. Any keys that were not previously "pressed" with `keydn` will have no effect. A bare `keyup` command with no modifiers or keys will release everything that was previously pressed.
Example:
```
keyup M_LEFTSHIFT A B C D E F
keyup # release all keys
```

### press
The `press` command presses and releases a single key, with any number of optional modifiers. The keypress time can be changed with the `press_time` command and the delay after release can be changed with the `interkey_time` command.
Example:
```
press M_LEFTSHIFT A
press ENTER
press M_LEFTSHIFT
```

### type
The `type` command sends a sequence of alphanumeric key presses/releases to "type" a string. The string must be enclosed in double quotes. The string can contain alphanumeric characters, whitespace, and special characters.

The keypress time can be changed with the `press_time` command. The `type` command will infer and automatically add shift modifiers when needed, so you can type characters and symbols as you expect to see them.

Special character handling:
- Tab literals in the string are typed as TAB key presses
- Escape sequences are supported: `\t` (TAB), `\n` (ENTER), `\\` (\), `\"` (")
- All common symbols are supported: `!@#$%^&*()_+-=[]{}|;:'"<>?/~`

To include double quotes within the string, escape them with backslashes: `\"`. For example, to type `He said "Hello"`, use `type "He said \"Hello\""`.
Example:
```
type "The quick brown fox jumps over the lazy dog!"
type "He said \"Hello\" to me"
type "Name:\tJohn\nAge:\t25"
type "Path: C:\\Users\\John\\Documents"
type "Math: 2 + 2 = 4, Score: 95%"
type "Code: if (x < y) { return true; }"
press ENTER
```

### repeat
The `repeat` command repeats, the specified number of times, all commands that follow it inside braces. You can nest `repeat` commands up to 256 levels deep.
Example:
```
repeat 3 {
    press ENTER

    repeat 100 {
        press DOWN
    }
}

press ENTER # This command is not repeated.
```

## Key definitions
This section defines the key names you can use with commands such as `keydn` and `press`. They are case sensitive.

### Modifiers
M_LEFTCTRL M_LEFTSHIFT M_LEFTALT M_LEFTGUI
M_RIGHTCTRL M_RIGHTSHIFT M_RIGHTALT M_RIGHTGUI

### Alphanumeric Keys
Alphanumeric keys are specified as they appear on a keyboard:
A B C D E F G H I J K L M N O P Q R S T U V W X Y Z
1 2 3 4 5 6 7 8 9 0
` - = [ ] \ ; ' , . /

### Special Keys
ENTER
ESCAPE
BACKSPACE DELETE
TAB SPACE
NONUS_HASH
CAPSLOCK SCROLLLOCK NUMLOCK
PAUSE
INSERT
HOME
PAGEUP PAGEDOWN
END
APPLICATION
MENU

### Numpad Keys
KP_SLASH
KP_ASTERISK
KP_MINUS
KP_PLUS
KP_ENTER
KP_1 KP_2 KP_3 KP_4 KP_5 KP_6 KP_7 KP_8 KP_9 KP_0
KP_DOT
NONUS_BACKSLASH

### Arrow Keys
RIGHT LEFT DOWN UP

### Function Keys
F1 F2 F3 F4 F5 F6 F7 F8 F9 F10 F11 F12
F13 F14 F15 F16 F17 F18 F19 F20 F21 F22 F23 F24

### International Keys
HENKAN MUHENKAN KATAKANAHIRAGANA HANGEUL HANJA

### System Keys
POWER SLEEP WAKE

### Modifier Keys
Typically, you would use the `M_` modifiers, which are sent as modifier bitmasks in the HID report. These versions will send the modifier as a key in the HID report's key data.
LEFTCTRL LEFTSHIFT LEFTALT LEFTMETA
RIGHTCTRL RIGHTSHIFT RIGHTALT RIGHTMETA

### Media Keys
MEDIA_PLAY_PAUSE MEDIA_STOP
MEDIA_PREVIOUS MEDIA_NEXT 
MEDIA_VOLUME_UP MEDIA_VOLUME_DOWN MEDIA_MUTE
MEDIA_EJECT
MEDIA_RECORD
MEDIA_REWIND MEDIA_FAST_FORWARD

### Consumer Keys
CALCULATOR
MYCOMPUTER
WWW_SEARCH WWW_HOME WWW_BACK WWW_FORWARD WWW_STOP WWW_REFRESH WWW_FAVORITES
MAIL
COMPOSE
BROWSER_BACK BROWSER_FORWARD BROWSER_REFRESH BROWSER_STOP BROWSER_SEARCH BROWSER_FAVORITES BROWSER_HOME
GAME
CHAT
ZOOM
PRESENTATION
SPREADSHEET
LANGUAGE

# ODKeyScript Virtual Machine
The ODKeyScript virtual machine executes bytecode generated by the compiler.
The VM always begins execution of a new program by clearing all internal state. If the state indicates that any keys/modifiers remain pressed, it will send a HID report to release them. Also, at the end of a program, if any keys remain pressed, the VM will release them.

## Virtual Machine
The VM executes opcodes out of a program memory array, which has a 32-bit "address" space, addressed in bytes. The addresses are zero-based indexes into the array. Any opcodes that modify the program counter will be bounds-checked by the VM implementation and, if the program counter runs off the end of the program memory array, the VM will raise an error and halt.

The program memory array is bounded by the size of the program currently loaded into it. It may reside in RAM or FLASH as long as it can be accessed via a base pointer, indexed with a zero-based program counter.

The VM maintains the following state:
- **Program Counter (PC)**: 32 bit address of current instruction
- **Zero Flag**: 1 bit flag that's set when an instruction results in zero
- **Counter State**: 512 byte counter space (256 2-byte counter variables)
- **Key State**: 6 byte array to track currently-pressed keys
- **Modifier State**: 8 bit bitmap tracking currently-pressed modifiers

## Opcode Definitions
Each opcode is a single byte, followed by any required operands.
```
0x10: KEYDN <mod> <count> <keys> # Press keys with modifiers (clears Zero Flag)
                                 # <mod>: 1-byte modifier bitmask
                                 # <count>: 1-byte count of key codes
                                 # <keys>: 0-6 bytes of key codes

0x11: KEYUP <mod> <count> <keys> # Release keys with modifiers (clears Zero Flag)
                                 # <mod>: 1-byte modifier bitmask  
                                 # <count>: 1-byte count of key codes
                                 # <keys>: 0-6 bytes of key codes

0x12: KEYUP_ALL                  # Release all currently pressed keys (clears Zero Flag)

0x13: WAIT <ms>                  # Wait for a specified number milliseconds (clears Zero Flag)
                                 # <ms> 2-byte number of milliseconds to wait

0x14: SET_COUNTER <index> <val>  # Set a counter variable to a value (clears Zero Flag)
                                 # <index>: 1-byte index into the counter state space
                                 # <value>: 2-byte value to set the counter to

0x15: DEC <index>                # Decrement a counter variable and set the Zero Flag if the new value is zero
                                 # <index>: 1-byte index into the counter state space

0x16: JNZ <address>              # Set the Program Counter to the specified address if the Zero Flag is not set (clears Zero Flag)
                                 # <address> 4-byte address, which is an index into the program's byte array in memory
```

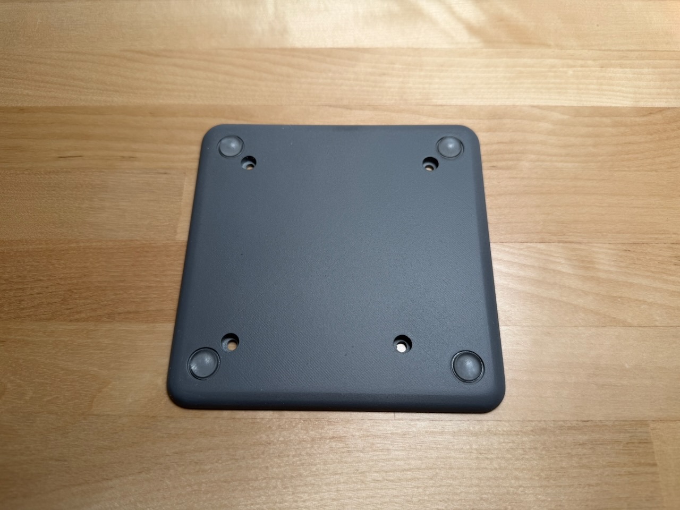
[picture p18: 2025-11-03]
docs/media/img-bottom-plate.jpeg

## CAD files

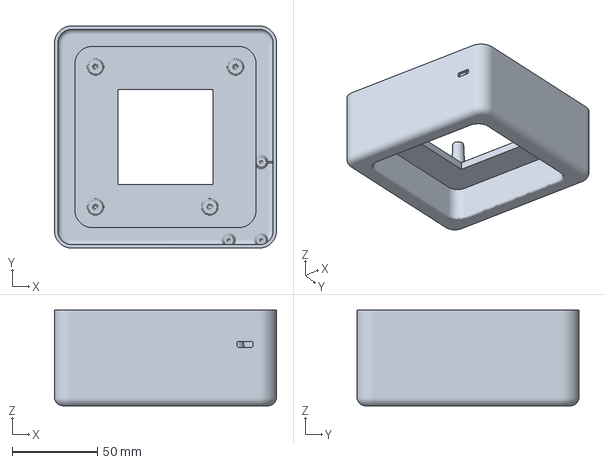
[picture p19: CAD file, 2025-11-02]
cad/3d/KeyBase-Top.3mf
130.0 x 130.0 x 56.0 mm

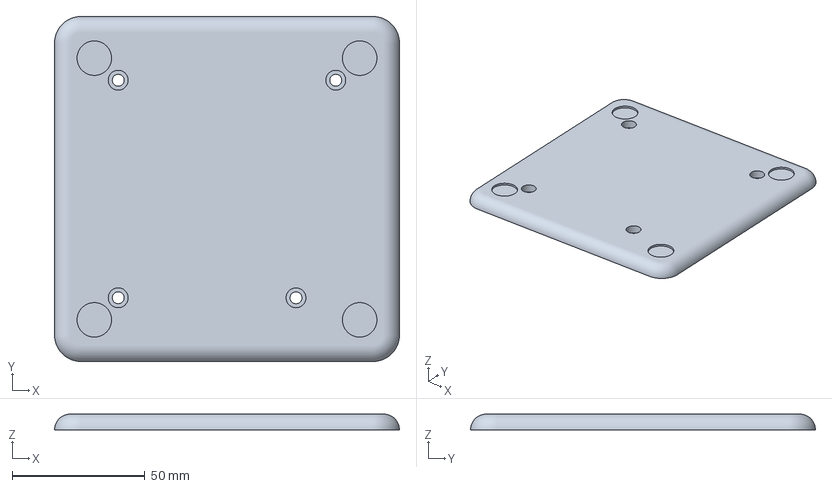
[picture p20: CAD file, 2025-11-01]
cad/3d/KeyBase-Bottom.3mf
130.0 x 130.0 x 6.00 mm

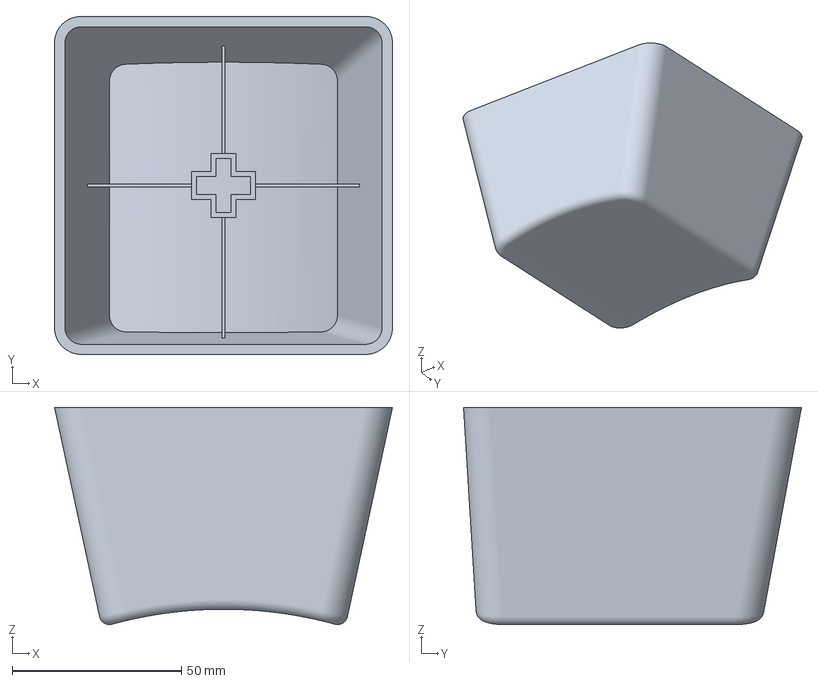
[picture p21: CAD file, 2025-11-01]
cad/3d/Keycap.3mf
100.0 x 100.0 x 64.2 mm

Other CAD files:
cad/3d/ODKey v29.f3d

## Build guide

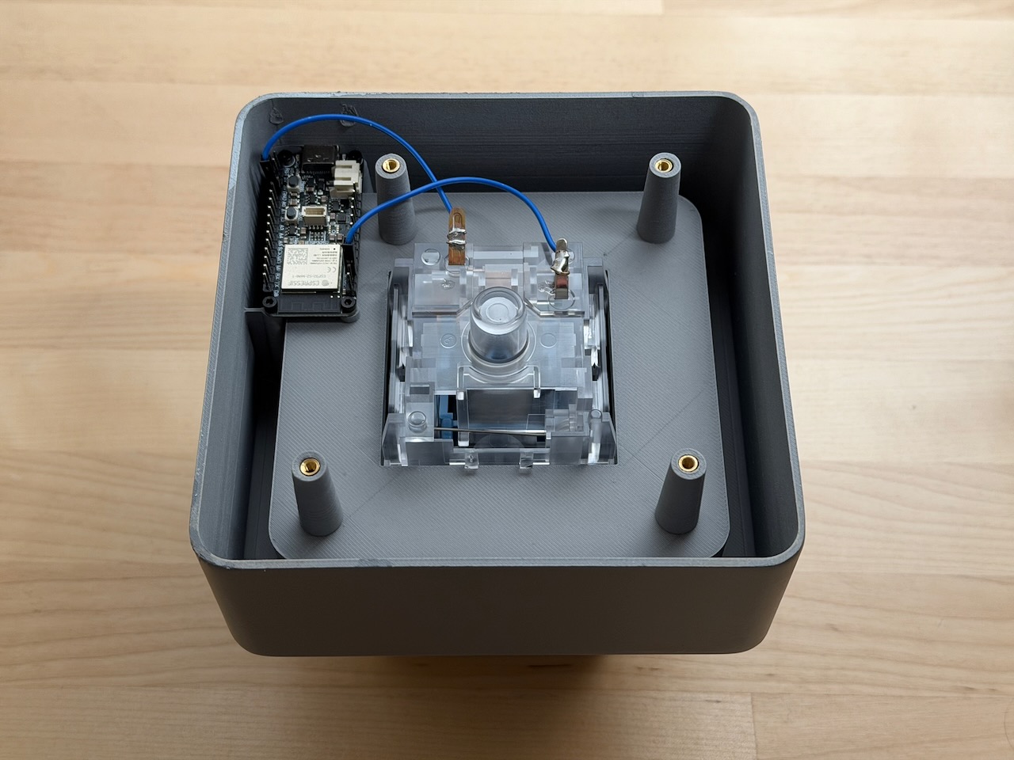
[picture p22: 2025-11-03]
docs/media/img-assembly.jpeg

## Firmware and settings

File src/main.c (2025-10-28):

#include "app.h"
#include "esp_log.h"
#include "freertos/FreeRTOS.h"
#include "freertos/task.h"
#include "log_buffer.h"

static const char *TAG = "main";

void app_main() {
    // Initialize log buffer first to capture all logs from startup
    if (!log_buffer_init()) {
        ESP_LOGE(TAG, "Failed to initialize log buffer");
        return;
    }

    ESP_LOGI(TAG, "Starting ODKey");

    if (!app_init()) {
        ESP_LOGE(TAG, "System initialization failed");
        return;
    }

    // Application is now event-driven - the main task can exit now
    ESP_LOGI(TAG, "ODKey initialized successfully, main task exiting. Godspeed!");
}

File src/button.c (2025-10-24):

#include "button.h"
#include "driver/gpio.h"
#include "esp_log.h"
#include "freertos/FreeRTOS.h"
#include "freertos/timers.h"
#include "nvs.h"
#include "nvs_odkey.h"
#include "program.h"

static const char *TAG = "button";

#define BUTTON_DEFAULT_DEBOUNCE_MS 50
#define BUTTON_DEFAULT_REPEAT_DELAY_MS 225

// Forward declarations
static void program_completion_callback(void *arg);

static struct {
    uint8_t gpio_pin;
    uint32_t debounce_ms;
    uint32_t repeat_delay_ms;
    TimerHandle_t button_timer;
    bool interrupt_enabled;
} g_button_state = {0};

// ISR handler
static void IRAM_ATTR button_isr_handler(void *arg) {
    (void)arg;

    // Disable interrupt temporarily
    gpio_intr_disable(g_button_state.gpio_pin);
    g_button_state.interrupt_enabled = false;

    // Reconfigure timer period for debounce and start timer
    xTimerChangePeriodFromISR(
        g_button_state.button_timer, pdMS_TO_TICKS(g_button_state.debounce_ms), NULL);
    xTimerStartFromISR(g_button_state.button_timer, NULL);
}

// Button timer callback - handles debounce and restart delays
static void button_timer_callback(TimerHandle_t xTimer) {
    (void)xTimer;

    // Check if button is still pressed (active low with pull-up)
    int level = gpio_get_level(g_button_state.gpio_pin);

    if (level == 0) {  // Button still pressed
        ESP_LOGI(TAG, "Button pressed/held, starting flash program execution");
        // Execute flash program with completion callback for auto-restart
        if (!program_execute(PROGRAM_TYPE_FLASH, program_completion_callback, NULL)) {
            ESP_LOGW(TAG, "Failed to execute flash program");
        }
    } else {
        ESP_LOGI(TAG, "Button released");
        // Button released - re-enable interrupts for next press
        if (!g_button_state.interrupt_enabled) {
            ESP_LOGI(TAG, "Re-enabling interrupts");
            gpio_intr_enable(g_button_state.gpio_pin);
            g_button_state.interrupt_enabled = true;
        }
    }
}

// Program completion callback - checks if button is still pressed and starts restart
// timer if so
static void program_completion_callback(void *arg) {
    (void)arg;

    // Check if button is still pressed (active low with pull-up)
    int level = gpio_get_level(g_button_state.gpio_pin);

    if (level == 0) {  // Button still pressed
        ESP_LOGI(TAG,
                 "Button still pressed, starting restart timer (%lu ms)",
                 (unsigned long)g_button_state.repeat_delay_ms);
        // Stop timer, reconfigure period for restart delay, then start
        xTimerStop(g_button_state.button_timer, 0);
        xTimerChangePeriod(g_button_state.button_timer,
                           pdMS_TO_TICKS(g_button_state.repeat_delay_ms),
                           0);
        xTimerStart(g_button_state.button_timer, 0);
    } else {
        ESP_LOGI(TAG, "Button released");
        // Button released - re-enable interrupts for next press
        if (!g_button_state.interrupt_enabled) {
            ESP_LOGI(TAG, "Re-enabling interrupts");
            gpio_intr_enable(g_button_state.gpio_pin);
            g_button_state.interrupt_enabled = true;
        }
    }
}

bool button_init(uint8_t gpio_pin) {
    // Read configuration from NVS with defaults
    nvs_handle_t nvs_handle;
    esp_err_t ret = nvs_open(NVS_NAMESPACE, NVS_READONLY, &nvs_handle);
    if (ret != ESP_OK) {
        ESP_LOGE(TAG, "Failed to open NVS: %s", esp_err_to_name(ret));
        return false;
    }

    // Read debounce delay with default
    uint32_t debounce_ms = BUTTON_DEFAULT_DEBOUNCE_MS;
    size_t required_size = sizeof(debounce_ms);
    ret = nvs_get_blob(
        nvs_handle, NVS_KEY_BUTTON_DEBOUNCE_MS, &debounce_ms, &required_size);
    if (ret == ESP_ERR_NVS_NOT_FOUND) {
        ESP_LOGD(TAG,
                 "Button debounce not found in NVS, using default %lu ms",
                 (unsigned long)debounce_ms);
    } else if (ret != ESP_OK) {
        ESP_LOGW(
            TAG, "Failed to read button debounce from NVS: %s", esp_err_to_name(ret));
    }

    // Read repeat delay with default
    uint32_t repeat_delay_ms = BUTTON_DEFAULT_REPEAT_DELAY_MS;
    required_size = sizeof(repeat_delay_ms);
    ret = nvs_get_blob(
        nvs_handle, NVS_KEY_BUTTON_REPEAT_DELAY_MS, &repeat_delay_ms, &required_size);
    if (ret == ESP_ERR_NVS_NOT_FOUND) {
        ESP_LOGD(TAG,
                 "Button repeat delay not found in NVS, using default %lu ms",
                 (unsigned long)repeat_delay_ms);
    } else if (ret != ESP_OK) {
        ESP_LOGW(TAG,
                 "Failed to read button repeat delay from NVS: %s",
                 esp_err_to_name(ret));
    }

    nvs_close(nvs_handle);

    if (debounce_ms == 0) {
        ESP_LOGE(TAG, "Debounce time must be greater than 0");
        return false;
    }

    if (repeat_delay_ms == 0) {
        ESP_LOGE(TAG, "Repeat delay must be greater than 0");
        return false;
    }

    // Store configuration
    g_button_state.gpio_pin = gpio_pin;
    g_button_state.debounce_ms = debounce_ms;
    g_button_state.repeat_delay_ms = repeat_delay_ms;
    g_button_state.interrupt_enabled = false;

    // Configure GPIO
    gpio_config_t io_conf = {
        .pin_bit_mask = (1ULL << gpio_pin),
        .mode = GPIO_MODE_INPUT,
        .pull_up_en = GPIO_PULLUP_ENABLE,
        .pull_down_en = GPIO_PULLDOWN_DISABLE,
        .intr_type = GPIO_INTR_NEGEDGE,  // Falling edge (button press)
    };

    ret = gpio_config(&io_conf);
    if (ret != ESP_OK) {
        ESP_LOGE(
            TAG, "Failed to configure GPIO %d: %s", gpio_pin, esp_err_to_name(ret));
        return false;
    }

    // Create unified button timer (will be reconfigured for different delays)
    g_button_state.button_timer =
        xTimerCreate("button_timer",
                     pdMS_TO_TICKS(debounce_ms),  // Initial period
                     pdFALSE,                     // One-shot timer
                     NULL,
                     button_timer_callback);

    if (g_button_state.button_timer == NULL) {
        ESP_LOGE(TAG, "Failed to create button timer");
        return false;
    }

    // Install ISR service
    ret = gpio_install_isr_service(0);
    if (ret != ESP_OK && ret != ESP_ERR_INVALID_STATE) {
        ESP_LOGE(TAG, "Failed to install ISR service: %s", esp_err_to_name(ret));
        xTimerDelete(g_button_state.button_timer, 0);
        return false;
    }

    // Add ISR handler
    ret = gpio_isr_handler_add(gpio_pin, button_isr_handler, NULL);
    if (ret != ESP_OK) {
        ESP_LOGE(TAG, "Failed to add ISR handler: %s", esp_err_to_name(ret));
        xTimerDelete(g_button_state.button_timer, 0);
        return false;
    }

    // Enable interrupt
    gpio_intr_enable(gpio_pin);
    g_button_state.interrupt_enabled = true;
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

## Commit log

2025-10-13 Restructured, fixed, and tested VM!
    [main.c]
2025-10-13 Untested program storage space and API
    [partitions.csv]
2025-10-14 Button working with the new virtual machine task.
2025-10-16 Fixed issues in uploader and attempting to send when USB not ready.
    [main.c]
2025-10-22 Prevent program execution while write in progress
    [app.c]
2025-10-22 rename: button_handler -> button
    Some other minor naming/comment changes.
2025-10-23 Added a place to stage scripts that don't get committed.
2025-10-24 Don't fail app on networking service init failures.
    [app.c]
2025-10-24 Fix potential, but unlikely, race condition.
    [button.c]
2025-10-24 Edge-case bounds check.
2025-10-25 Clean up unnecessary complexity of session buffers
    The http server is not multi-threaded, so it can simply use a single global buffer.
2025-10-28 Added switch link to readme
2025-11-01 Added images/cad
    [KeyBase-Bottom.3mf, KeyBase-Top.3mf, Keycap.3mf]
2025-11-02 Improved KeyBase CAD
    Fixed issues with mounting holes
    [KeyBase-Top.3mf]
2025-11-02 Added F3D CAD file
    [ODKey v27.f3d]
2025-11-03 Writeup and media
    [ODKey v27.f3d, ODKey v29.f3d]
